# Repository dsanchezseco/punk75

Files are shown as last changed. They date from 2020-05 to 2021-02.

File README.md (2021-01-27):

# punk75
Ortholinear keyboard with 75 keys and all components through hole

Uses an ATmega32A-PU and USB-C.

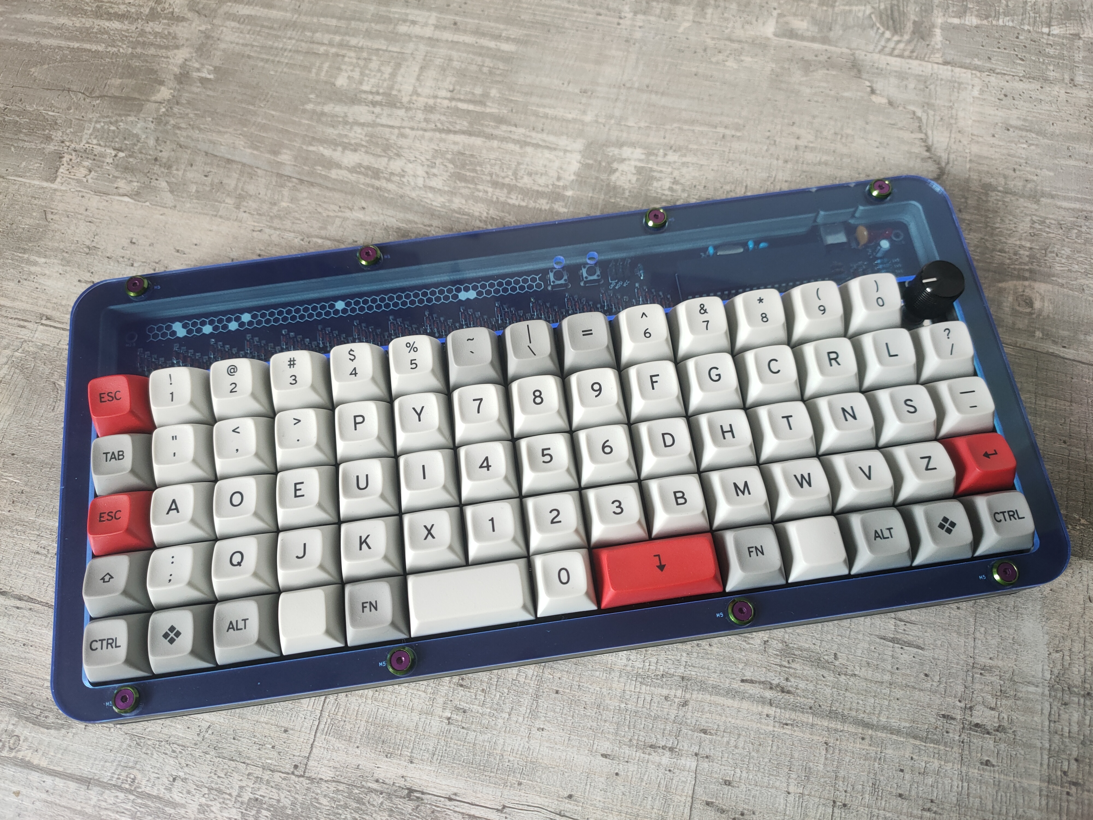
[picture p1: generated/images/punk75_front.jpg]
full keyboard front

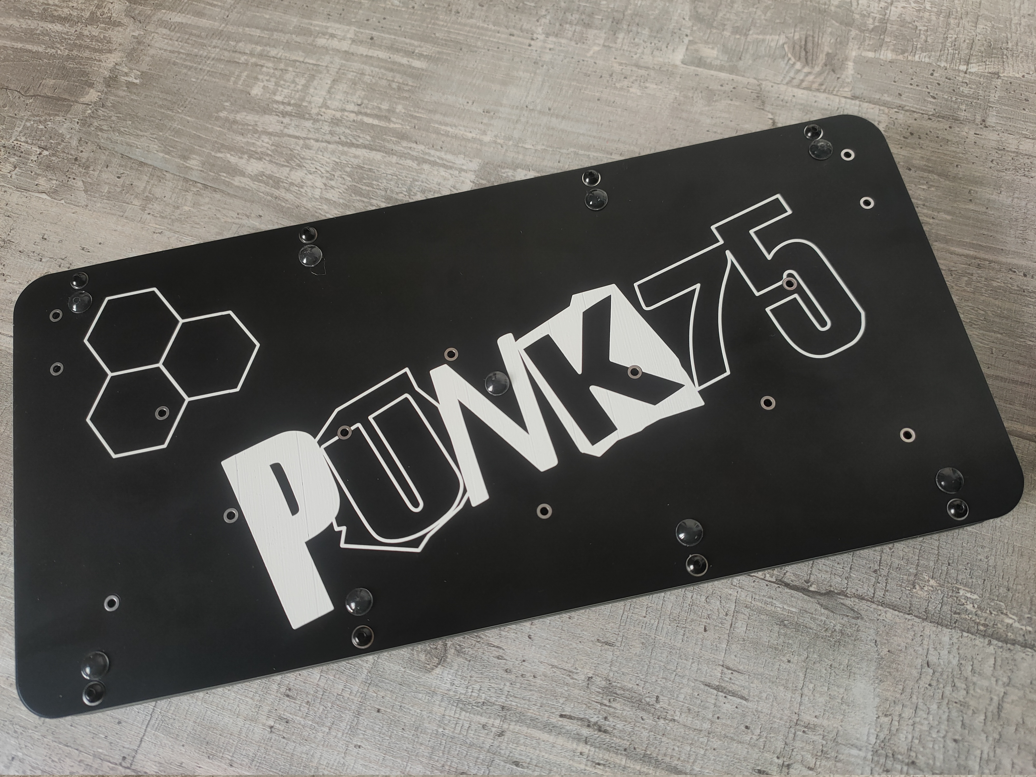
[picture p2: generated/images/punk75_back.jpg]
full keyboard back

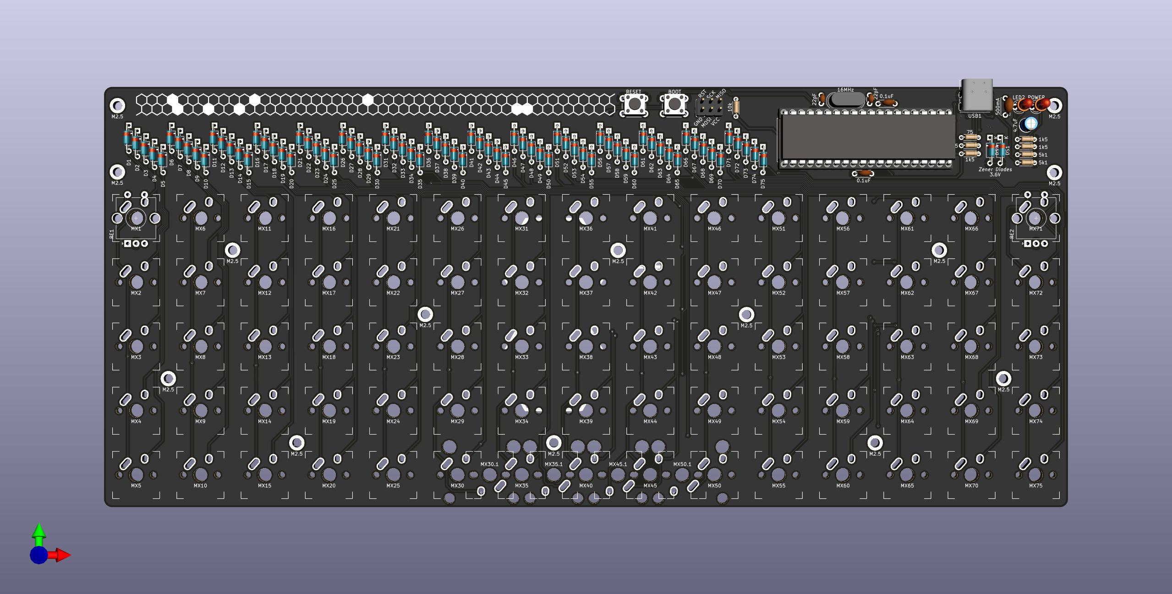
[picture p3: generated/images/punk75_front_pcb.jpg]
front of pcb

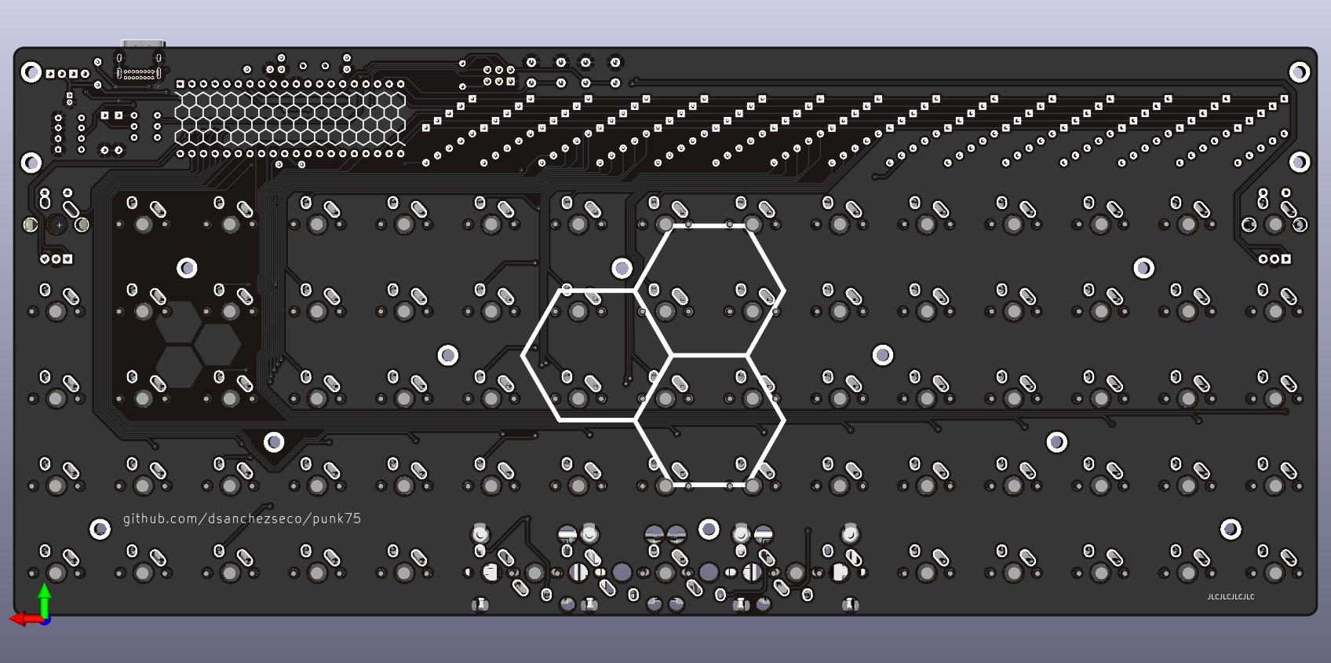
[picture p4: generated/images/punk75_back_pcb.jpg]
back of pcb

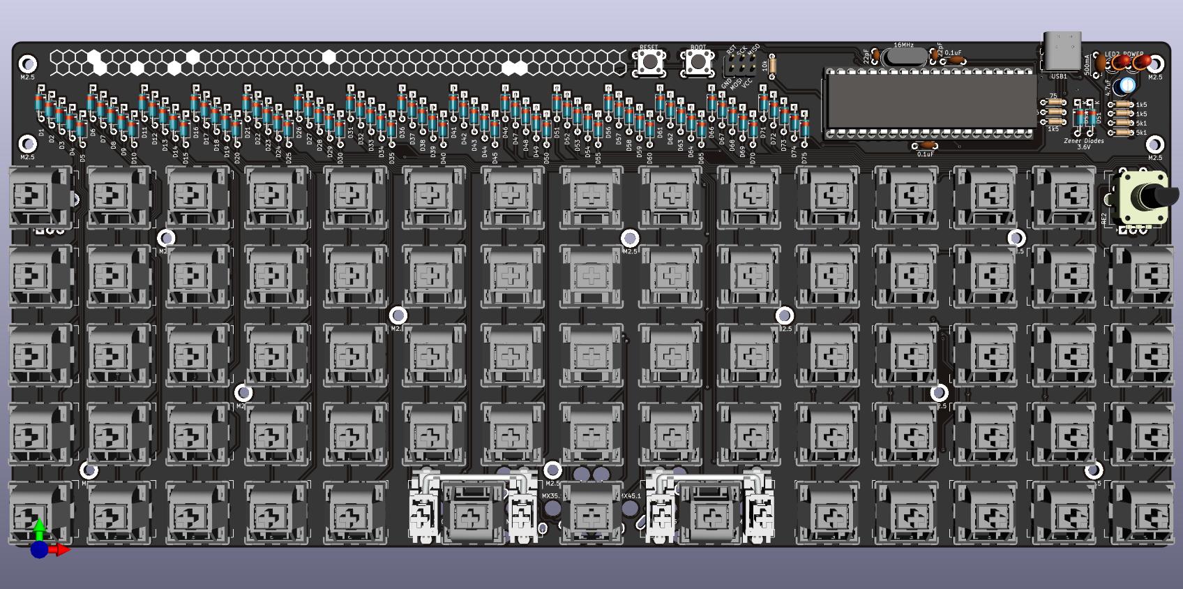
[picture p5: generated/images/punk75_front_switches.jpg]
with switches


# BOM list
[BOM list](https://octopart.com/bom-tool/D58T7Rv1)

# Building
[Building guide](https://github.com/dsanchezseco/punk75/blob/master/BUILDING.md)

# Bootloader flashing

Before being able to flash the keymap as regular in QMK using a USB we need to
flash the bootloader first. It is only needed to do this process once if the MCU
does not come already flashed with a bootloader.

Punk75 uses [USBasp](https://www.fischl.de/usbasp/) as bootloader.

To flash USBasp you'll need and *USBasp dongle* or a *pro micro/elite-c*.
Other methods not tested but may work.

To follow the process to flash the bootloader [go here](https://github.com/dsanchezseco/USBaspLoader)
and follow the instructions.

# Keymap flashing
There are two possibilities

## QMK toolbox
TODO

## CLI
TODO

# Cases

## PCB
[PCB case](https://github.com/dsanchezseco/punk75/blob/master/case/PCB/README.md)

## Acrylic
[Acrylic case](https://github.com/dsanchezseco/punk75/blob/master/case/sandwich/README.md)

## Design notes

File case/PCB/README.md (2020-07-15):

# Case made out of PCBs

This is an alternative to the acrylic case. It has the same dimenssions and form
but it is made out of (more) layers of PCBs instead of acrylic.

## Parts (top to bottom)

1. punk75_inner.zip - PCB - 4 needed - OPTIONAL FOR HI-PRO CASE
2. punk75_plate.zip - PCB
3. punk75_inner.zip - PCB - 5 needed
4. punk75_bottom.zip- PCB

This parts can be sourced from a PCB manufacturer with the .zip files of this
folder.

## Screws and Standoffs

1. x16 M3x6mm screws
2. x8  M3x10mm round standoffs of 5mm outside diameter
    (for the HI-PRO use M3x15mm)

## Assembly

For the assembly of all the parts we need to first place the switches on the
plate and then proceed to solder them to the keyboard PCB (solder first the
rotary encoders to the pcb if any).

Then we can proceed form bottom to top by screwing the spacers to the bottom and
inserting the inners in the standoffs. Notice the inners have breakable zone
where the USB port is placed, this need to be snipped or cut. Cut the needed
amount to fit your cable(is a bit tight, I have on mine 1 not cutted and 4 with
the cutout, test with yours).

Next place the plate and you are good to go.

If you have the HI-PRO place then the rest of the inners (not cutted) and screw
everything.

## Acrylic shield

Additionally two acrylic shields can be used to protect the electronic components.
One, a full shield (shield.dxf) can be used with the HI-PRO case (and with the
LO-PRO if the components are mounted low).

The other option is to use a half shield (half-shield.dxf) that instead of using
the rest of the case as support uses its own standoffs to held it down to the PCB.

This standoffs and screws for the half-shield are M2.5 size, use the lenght you
feel appropiate. You'll need 4 standoffs and 8 screws.

To know how to source this acrylic pieces refeer to the sandwich case README.md

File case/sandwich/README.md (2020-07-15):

# Acrylic High Profile case

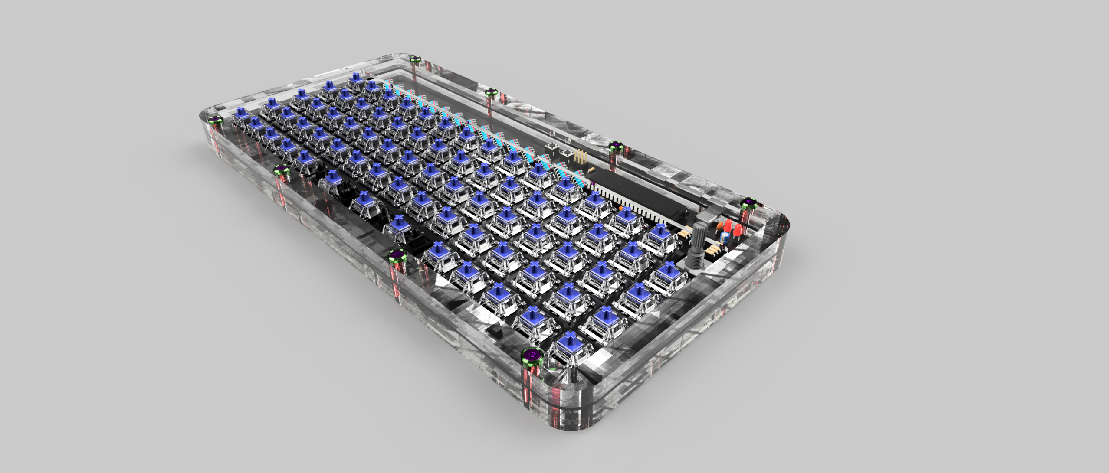
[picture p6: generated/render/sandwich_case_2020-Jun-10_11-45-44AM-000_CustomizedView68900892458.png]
sandwich case render


Case of sandwich style made out of acrylic(plate made out of Delrin for extra rigidity).

__I recommend using [Ponoko](https://www.ponoko.com/) to cut the pieces. They have all of the correct/required thicknesses and materials in stock and have the best pricing that I have found for multiple one-off parts. Use clear acrylic for the full range of thickness options and Delrin (POM) for the plate. For proper fit please ensure you use the correct dimensions and material thicknesses noted below. Other colors may be used, but of the colors may have limited thickness options, so you may have to narrow material results by thickness to see which colors are available for that size.__

__Ponoko's automatic size detection when uploading is not flawless, so be sure to manually enter the dimensions below.__

## Parts (top to bottom)

1. shield.dxf  - 307.7 x 146.6 - 2 mm thickness - acrylic
2. closed.dxf  - 307.7 x 146.6 - 3 mm thickness - acrylic
3. closed.dxf  - 307.7 x 146.6 - 3 mm thickness - acrylic
4. plate.dxf   - 307.7 x 146.6 - 1.5 mm thickness - *Delrin*
5. open.dxf    - 307.7 x 146.6 - 4.5 mm thickness - acrylic
6. closed.dxf  - 307.7 x 146.6 - 3 mm thickness - acrylic
7. bottom.dxf  - 307.7 x 146.6 - 3 mm thickness - acrylic

__Closed layer is used three times!__

You can choose any type of material/finish for the layers, but notice the required thicknes! For the plate layer Delrin is used because of the extra rigidity compared with regular acrylic, but it only comes in white or black.

## Screws and Standoffs

1. x16 M3x6 screws
2. x8  M3x15 round standoffs of 5mm outside diameter

#### Optional
If using conic screws as in the renders M3 conic washers (8mm) are also required.q

### Credits

Dimensions, intro and general form of the case taken from [coseyfannitutti](https://github.com/coseyfannitutti/discipline/blob/master/case/README.md)

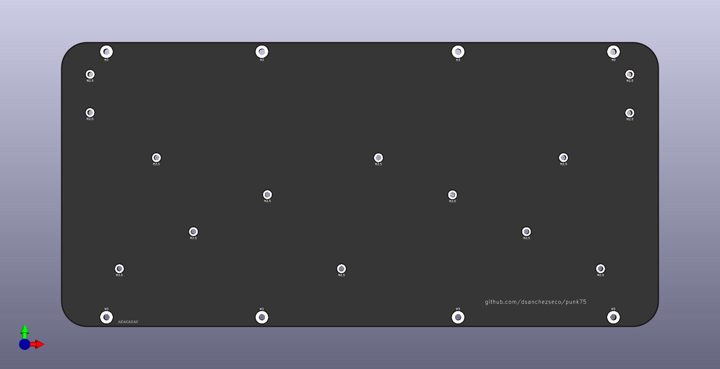
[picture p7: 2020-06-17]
generated/images/punk75_bottom_front.jpg

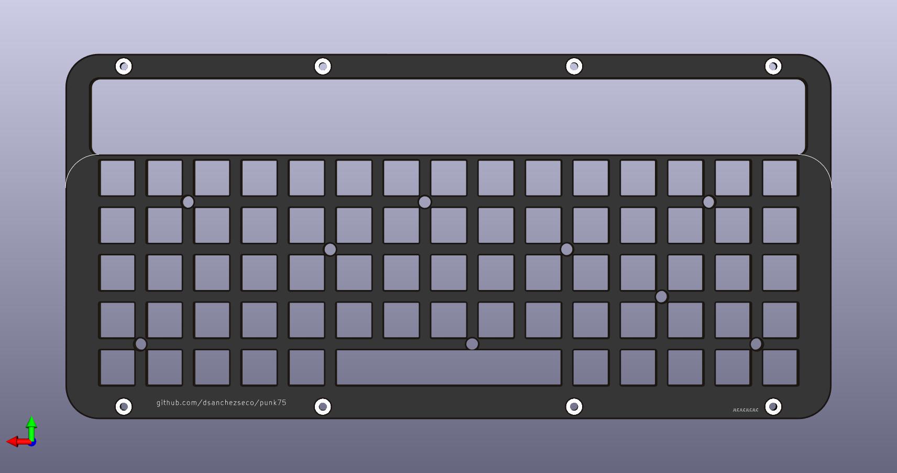
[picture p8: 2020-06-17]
generated/images/punk75_plate_back.jpg

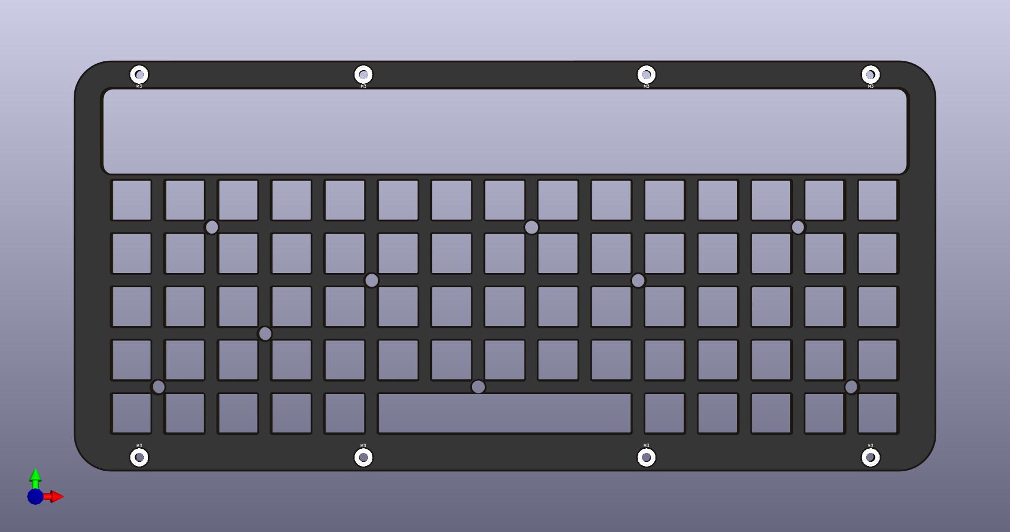
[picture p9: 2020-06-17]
generated/images/punk75_plate_front.jpg

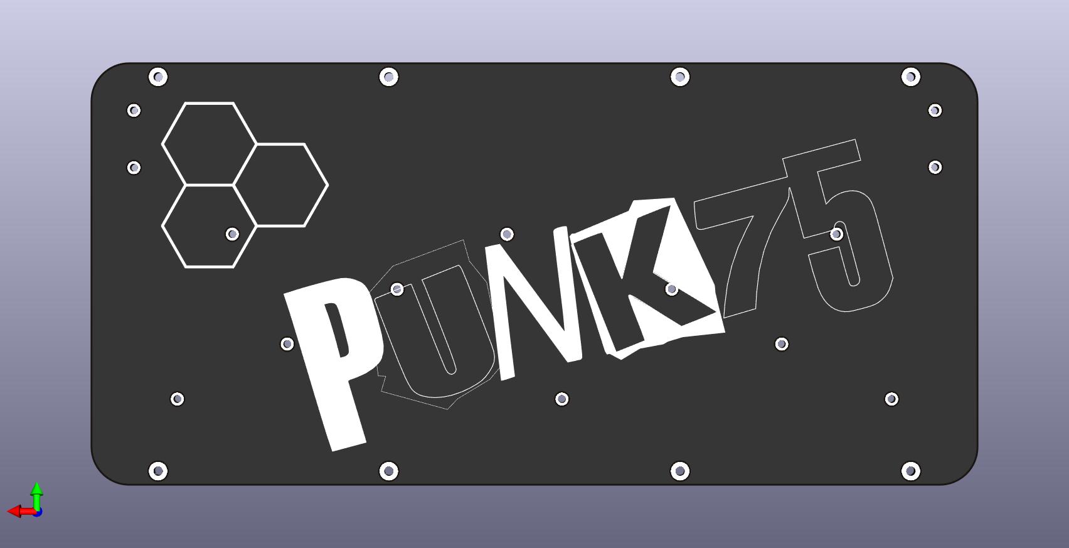
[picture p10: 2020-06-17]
generated/images/punk75_bottom_back.jpg

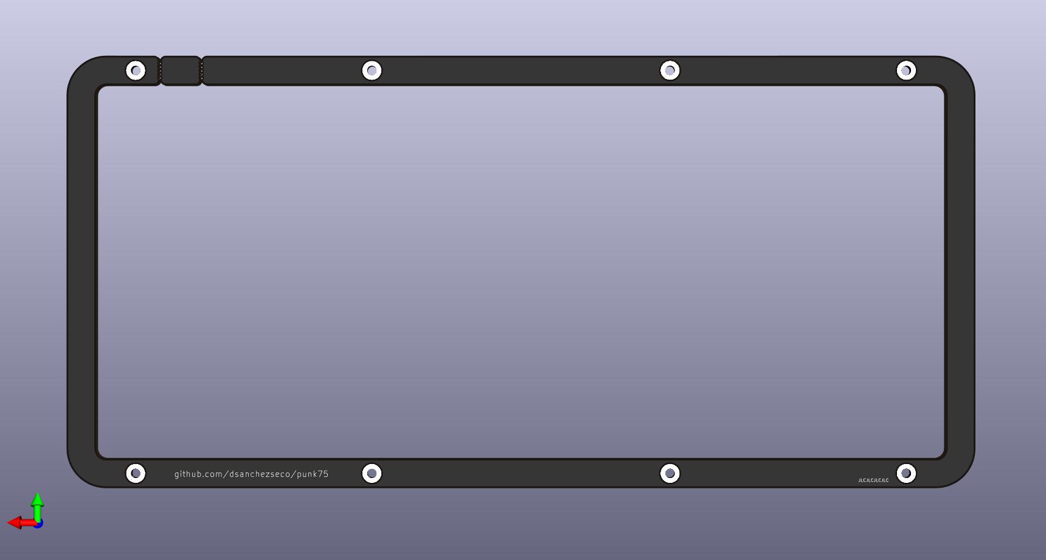
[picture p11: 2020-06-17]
generated/images/punk75_inner_back.jpg

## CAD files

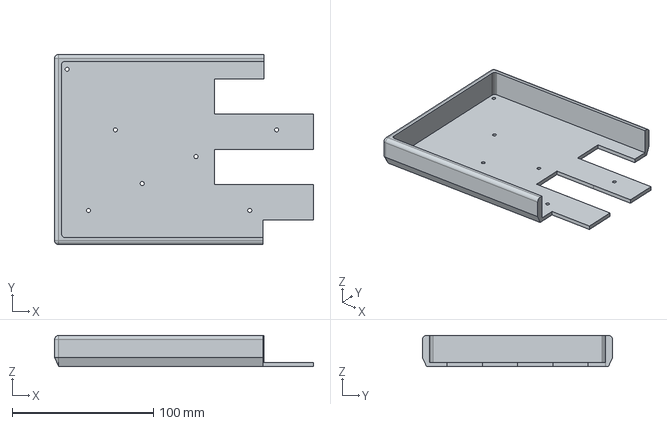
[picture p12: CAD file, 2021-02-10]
case/3D_Printed/Simple High Profile Case/Punk75 HP - Left Side.step
183.5 x 134.9 x 22.0 mm

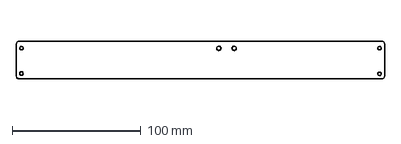
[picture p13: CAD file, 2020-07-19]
case/PCB/half-shield.dxf
285.8 x 29.4 mm

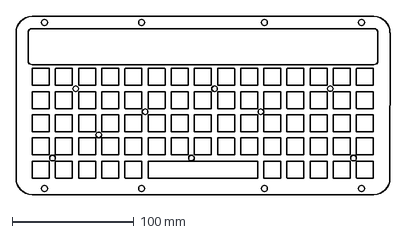
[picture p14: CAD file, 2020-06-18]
case/sandwich/plate.dxf
307.8 x 146.6 mm

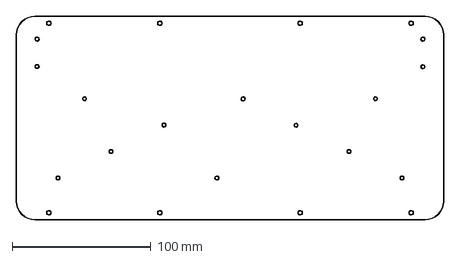
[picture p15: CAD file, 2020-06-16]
case/sandwich/bottom.dxf
307.8 x 146.6 mm

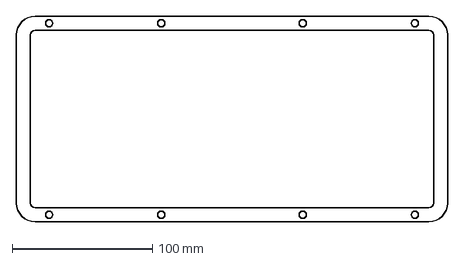
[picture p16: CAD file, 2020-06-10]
case/sandwich/closed.dxf
307.8 x 146.6 mm

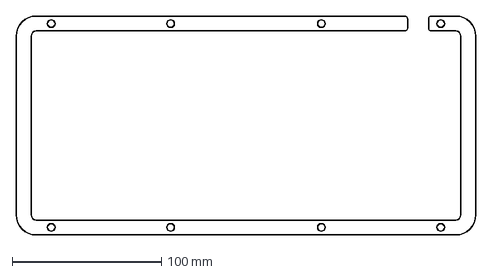
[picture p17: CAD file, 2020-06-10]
case/sandwich/open.dxf
307.8 x 146.6 mm

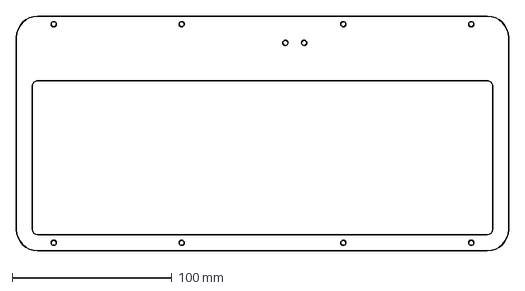
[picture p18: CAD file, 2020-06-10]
case/sandwich/shield.dxf
307.8 x 146.6 mm

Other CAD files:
case/3D_Printed/Simple High Profile Case/Punk75 HP - Right Side.step
case/PCB/shield.dxf
case/3D_Printed/Simple High Profile Case/Punk75 HP - Left Side.stl
case/3D_Printed/Simple High Profile Case/Punk75 HP - Right Side.stl

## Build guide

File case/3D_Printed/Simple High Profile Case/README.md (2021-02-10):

# 3d Printed Case Production and Assembly Notes

## Overview

The 3d printed cases in this directory should all follow these assembly instructions. They have also been designed to use the half shield .dxf here: https://github.com/dsanchezseco/punk75/blob/master/case/sandwich/half-shield.dxf

## Case Designer Index

| Case Design | Author |
|---|---|
| Simple High Profile Case | jmo808 |

## Sample Pics

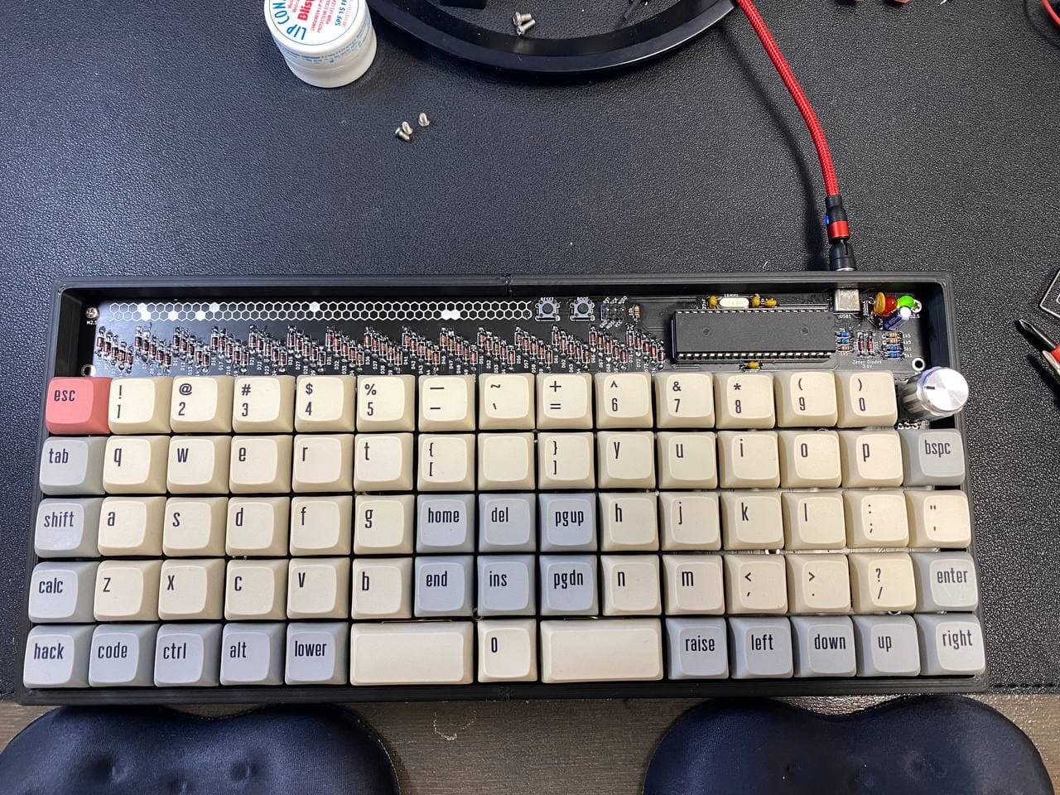
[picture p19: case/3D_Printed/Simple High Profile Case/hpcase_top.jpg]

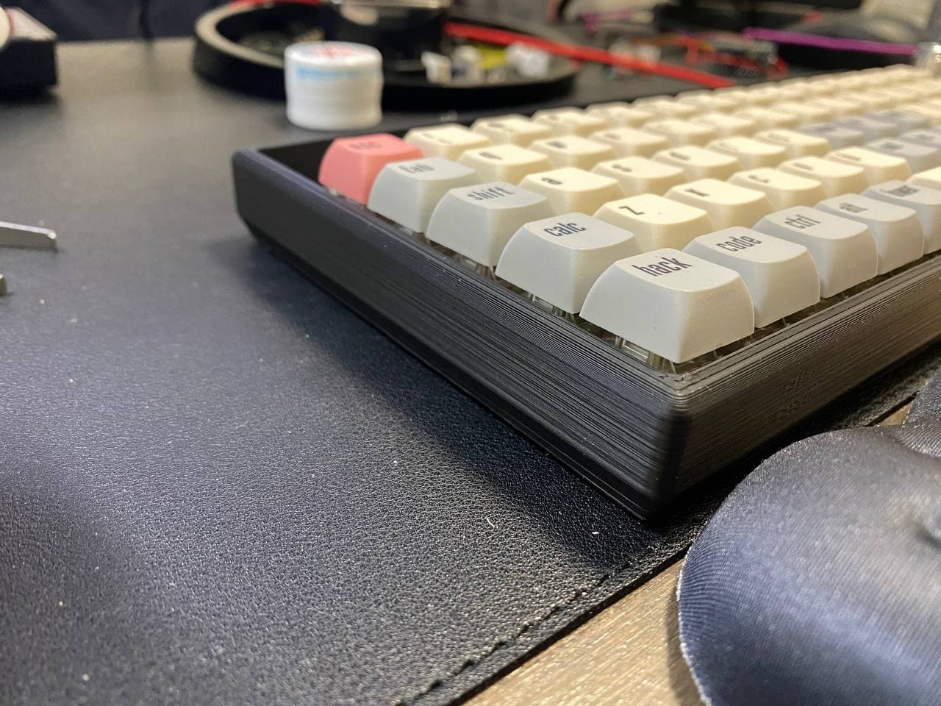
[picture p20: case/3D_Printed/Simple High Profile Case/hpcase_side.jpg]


## Required Parts

* (12) M2.5 5mm Standoffs
* (12) M2.5 6mm Pan/Button Head machine screws (for bottom of case to standoffs)
* (12) M2.5 3mm Pan/Button Head machine screws (for PCB to standoffs)

## Printing Settings

This was printed with .2 layer height. Lower layers will have a smoother appearance at the risk of much longer print time.

## Assembly Instructions

Once both halves are printed clean up any artifacts and "elephant foot" so that both halves fit nicely.

Install the standoffs with the 6mm screws then use the PCB to secure the halves together. Some filaments have more shrinkage than others and using the PCB as a guide will ensure that the case is assembled square. You will then have the opportunity to fill any gaps vs creating a case that is too small.

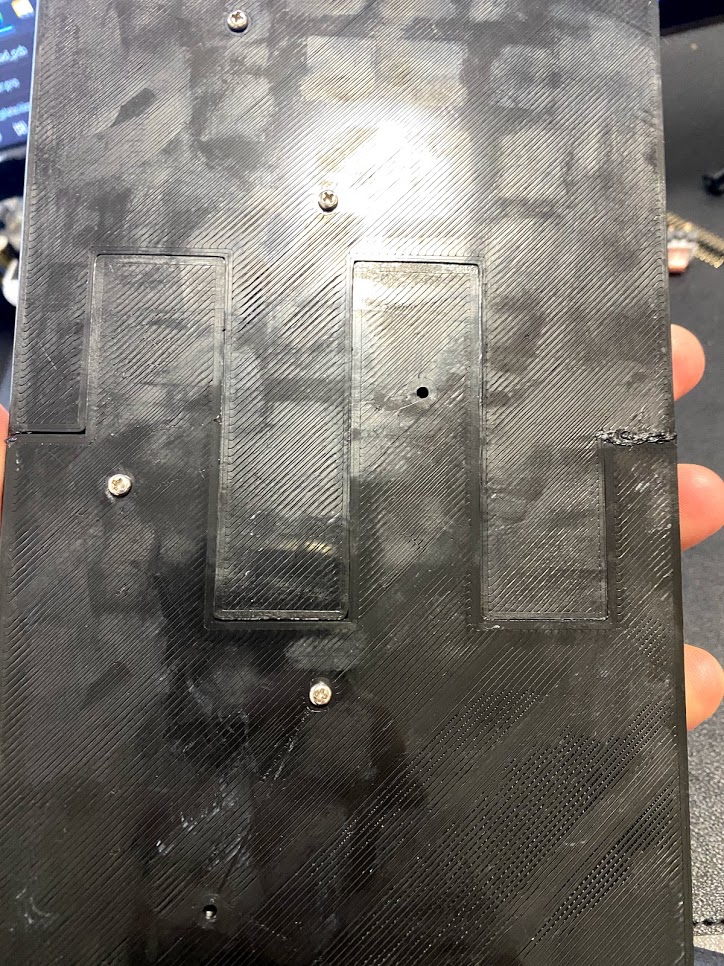
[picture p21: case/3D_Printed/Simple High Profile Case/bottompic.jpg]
Bottom View


Once the PCB is affixed to the standoffs on both halves you can either glue or friction weld the outside of the case together. Friction welding is recommended as it is more mechanically sound, but needs more significant post-processing if a more professional appearance is desired. If you are choosing to use the friction welding method, you will require a high speed handheld rotary tool.

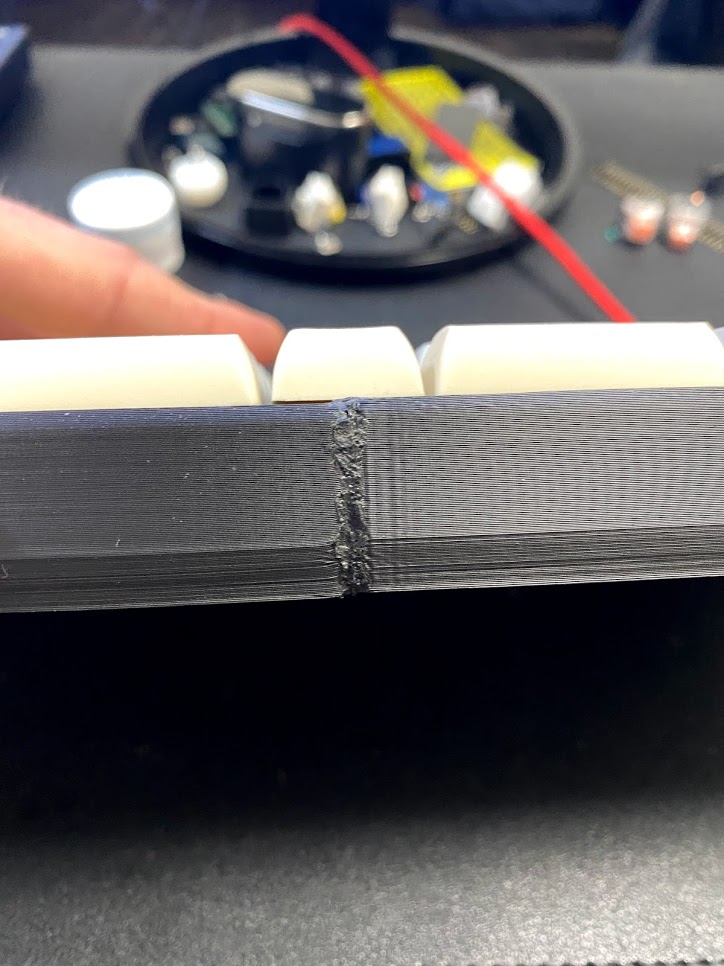
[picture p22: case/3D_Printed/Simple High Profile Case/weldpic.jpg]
Sample Weld Pic


The technique is shown here: https://www.youtube.com/watch?v=Pa2DoE3sirU.

If the only filament you have is 1.75mm you will need to insert two pieces of filament and cut one flush to the collet of your rotary tool this will secure the 1.75mm filament vs. going and buying 2.85mm filament just to friction weld. Left over bits on filament rolls are a perfect source of friction welding material.

**SAFETY NOTE**: *Wear wrap around safety glasses or goggles when friction welding as bits of plastic can shoot out and injure you.*

Once the bottom of the case is welded you can remove the PCB and friction weld the inside of the case for added strength.

## Post Processing

For a more refined appearance I suggest sanding and polishing. My recommendation is to use an orbital sander with Abranet disks as they are much cooler than regular sanding disks and will prevent PLA from getting gummy. Start with 120 grit to remove layer lines, then move on to 220 grit, then 400 grit and follow up with wet hand sanding at 400 grit and final wet hand polishing at 2000 grit.

## Final Assembly

Re-install the populated PCB, install keycaps and enjoy!

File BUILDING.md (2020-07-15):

# Building guide
This file cover all the building(soldering) needed to get your punk75 up and running.

All the spots in the PCB are labeled with the value of the component that goes in that spot,
so it should be fairly easy, you only need to pay attention to the components that have orientation.

Start with the smallest components like the resistors. They have no orientation.
Then place the Zenner Diodes (DS1 & DS2), this two have orientation, so take care to match the line
of the component with the line(square hole) of the pcb.

Continue with the capacitors that go arround the MCU and the crystal, they have no orientation, pay
attention to leave room for the MCU that will be placed later.

Now place the LEDs, they have orientation, so put the shorter leg in the square hole.
The missing capacitor comes next and it also has orientation, the grey line/shorter leg goes in the grey hole.

Next place the fuse, it has no orientation.

Now comes the time for the MCU. You can choose to solder it directly to the PCB, it'll rest lower but if it breaks
would be way harder to replace. I recommend you to use the MCU socket. Pay attention to the orientation and match the
socket and MCU notches with the PCB painted one.

Then add the push buttons and the optional 3x2 pins.

Finish by soldering the USB-C port and its tiny pins(good luck), the flux and using a low amount of solder
is quite helpfull here.

Now you are ready to test your keyboard, connect a usb cable, check there's no smoke and the right LED powers on.
If you short the two pins of a switch and its diode the left LED should power on while held.

If everything went smooth you are ready to finish it by soldering the diodes(mind the orientation as in the zenners)
and the swithes.

Well done!

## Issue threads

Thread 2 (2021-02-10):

Simple High Profile 3d Printed Case

jmo808, 2021-02-10:
I've designed a simple high profile 3d printed case. It comes as two parts in order to print on most printers with alignment tabs for gluing/welding. Instead of posting it on Thingiverse I'd rather include it here in order to keep things together. I can profile STL and STEP file. If you are ok with incorporating the case in your repo, I will do a PR.

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

dsanchezseco, 2021-02-10:
Sure, go ahead, it looks awesome!! I'm regreting now not having a 3D printer :(

jmo808, 2021-02-10:
3d printers are almost as much of a time suck as mech keyboards so maybe it's a good thing you don't have one, though I definitely like having one! I will submit PR today sometime.

Closed 2021-02-10.

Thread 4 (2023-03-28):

Keypress issues

vialde, 2023-03-28:
Morning,

Just wanted to say how happy I am that you've open sourced this design...I really like it.  I've got a quick question.  I'm having issues with my build.  I've had the PCBs fab'd and soldered on all the components.  Flashed the firmware using the instructions in your other repo....everything looked good.  Unfortunately it's not registering keypresses.  I'm new to the Keyboard pcb game...I've done a few hand wired boards using pro micros, but I'm not sure what to troubleshoot here.  Both led's light up when the usb cable is plugged in...that's the only response I get.  Any thoughts or tips?
Cheers

dsanchezseco, 2023-04-03:
Hi! glad you like it and honored you build it!

The other repo is the bootloader, the only thing I can think of is that you might be missing the actual keymap.

it would be a regular QMK flash process now that you have the bootloader. One of the leds should blink when a keypress is registered. If I remember correctly with the bootloader only it just turned on to tell you the bootloader is correctly in.

It's being a while since I created and I barely remember the process 😅

vialde, 2023-04-19:
Hey, that might be the issue.  I thought the bootloader contained everything.  okay.  so the question is now...can I flash via the usb c or do I need to used the adapter again?

dsanchezseco, 2023-04-19:
USB-C just hold the boot button, plug it in or press reset, hold the boot a couple seconds more and the you are good to do the flash with QMK

-------- Original Message --------
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

dsanchezseco, 2023-04-19:
Is it working then?? Enjoy it!! I loved making and using it, i hope you do as well!

-------- Original Message --------
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

vialde, 2023-05-01:
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
Working like a charm!  Now for a case!

Closed 2023-05-01.

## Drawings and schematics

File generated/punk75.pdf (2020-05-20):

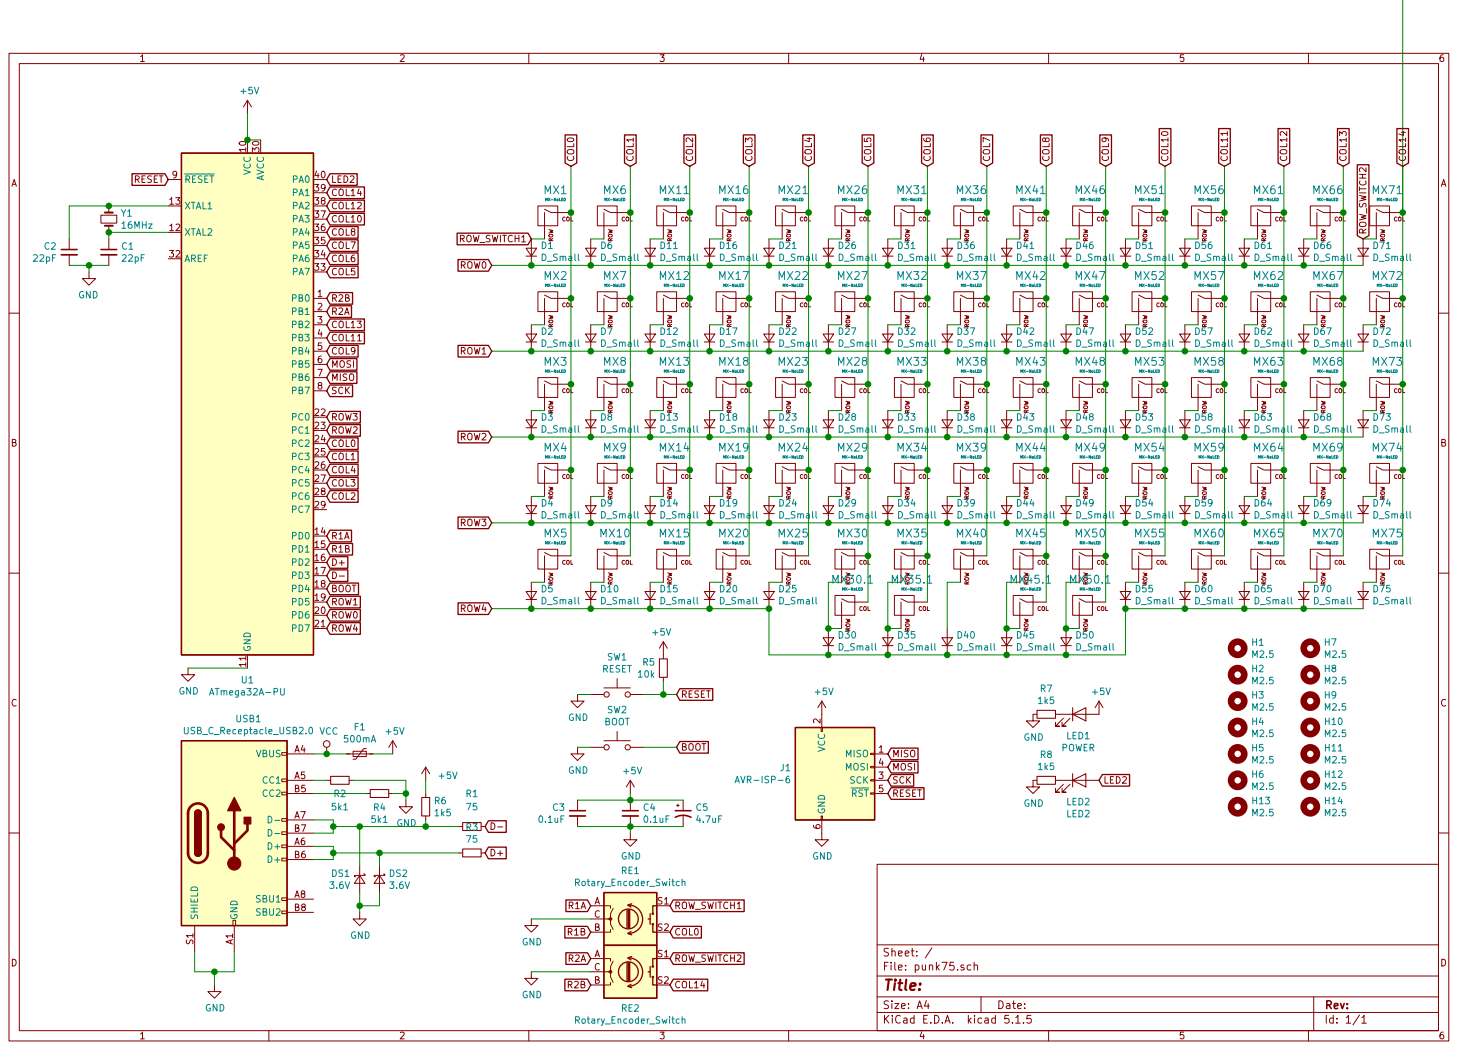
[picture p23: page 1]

MX-NoLED D72 D_Small COL ROW MX72

MX-NoLEDCOL ROW MX6
MX-NoLED D67 D_Small COL ROW MX8

MX-NoLED D22 D_Small COL ROW MX22
MX-NoLED D18 D_Small COL ROW MX18

MX-NoLED D27 D_Small COL ROW MX27

MX-NoLED D46 D_Small COL ROW MX46
MX-NoLED D48 D_Small COL ROW MX48

MX-NoLED D52 D_Small COL ROW MX52

MX-NoLED D57 D_Small COL ROW MX57

MX-NoLED D62 D_Small COL ROW MX62

D42 D_Small COL ROW MX32
MX-NoLED D34 D_Small COL ROW MX34

MX-NoLED COL ROW MX47
MX-NoLED D43 D_Small COL ROW MX43

MX-NoLED D54 D_Small COL ROW MX54
MX-NoLED COL ROW MX68
MX-NoLED D65 D_Small COL ROW MX65

MX-NoLED D23 D_Small COL ROW MX23

MX-NoLED D28 D_Small COL ROW MX28

MX-NoLED D47 D_Small D33 D_Small COL ROW MX33

MX-NoLED D38 D_Small COL ROW MX38

MX-NoLED D58 D_Small COL ROW MX58

MX-NoLED D63 D_Small COL ROW MX63

MX-NoLED D74 D_Small COL ROW MX74

MX-NoLED D39 D_Small COL ROW MX39

COL ROW MX13
MX-NoLED D20 D_Small COL ROW MX20

MX-NoLED D29 D_Small COL ROW MX29

MX-NoLED D49 D_Small COL ROW MX49

MX-NoLED D24 D_Small COL ROW MX14
MX-NoLED D15 D_Small COL ROW MX15

MX-NoLED D25 D_Small COL ROW MX25

MX-NoLED D40 D_Small COL ROW MX40

MX-NoLED D55 D_Small COL ROW MX55

MX-NoLED D60 D_Small COL ROW MX60

MX-NoLED D70 D_Small COL ROW MX70

2 SCK 3 MOSI 4 RST 5 GND

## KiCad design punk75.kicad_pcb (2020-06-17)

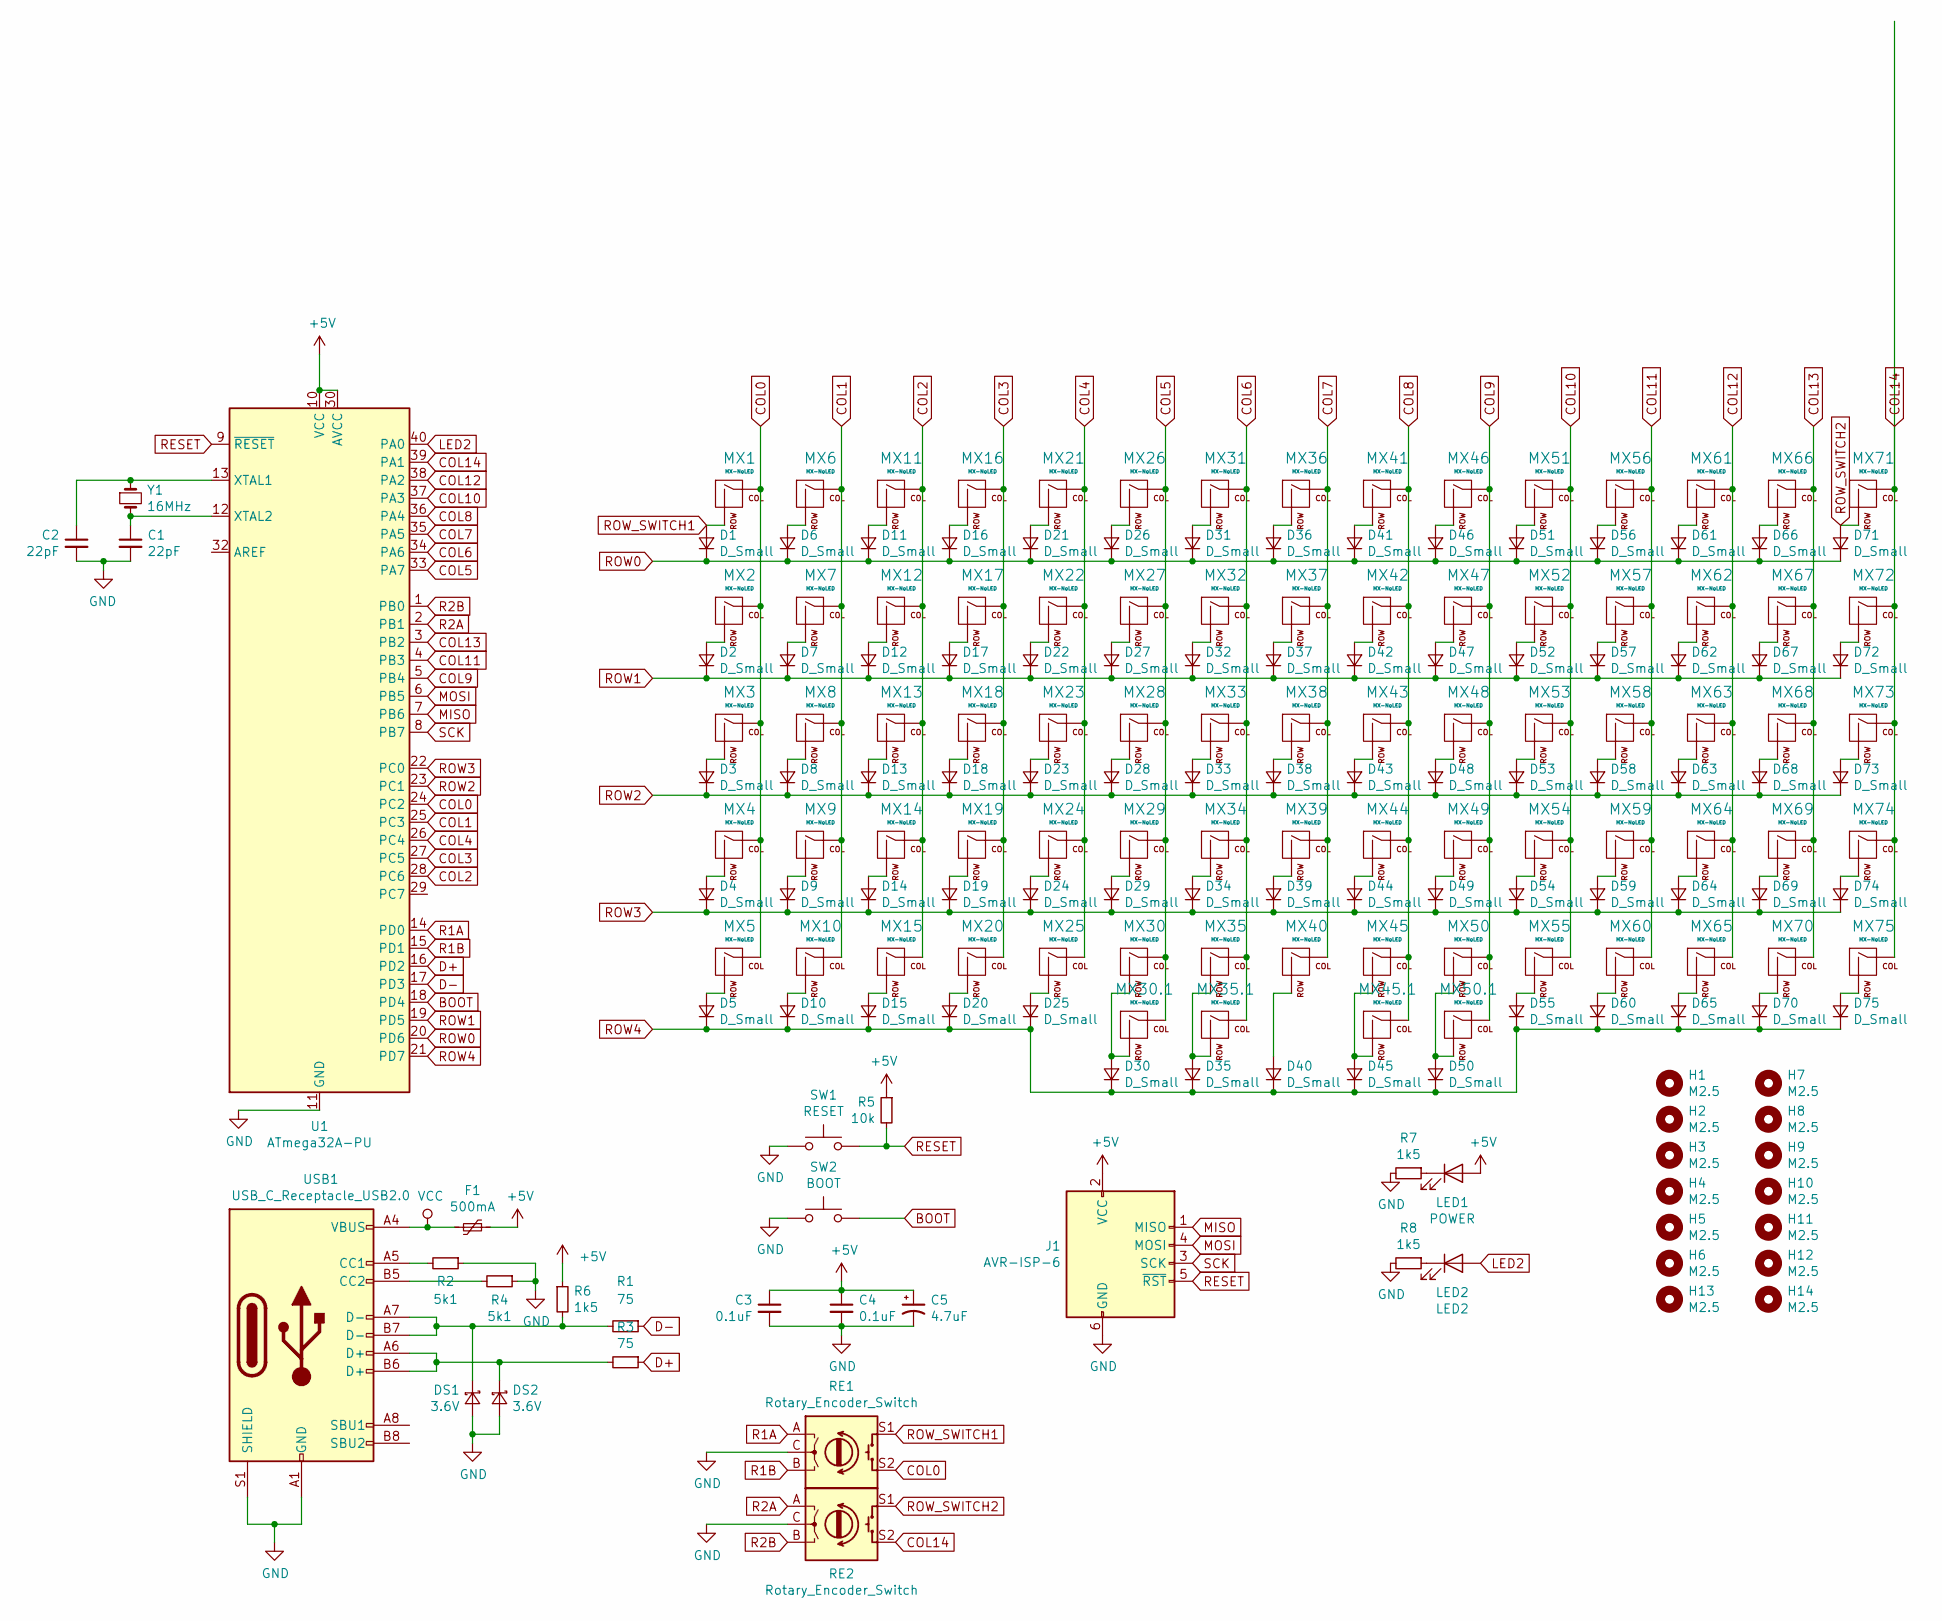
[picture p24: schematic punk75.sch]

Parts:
C1, C2: 22pF; C_Disc_D3.0mm_W1.6mm_P2.50mm
C3, C4: 0.1uF; C_Disc_D4.3mm_W1.9mm_P5.00mm
C5: 4.7uF; CP_Radial_D4.0mm_P1.50mm
D1, D2, D3, D4, D5, D6, D7, D8, D9, D10, D11, D12, D13, D14, D15, D16, D17, D18, D19, D20, D21, D22, D23, D24, D25, D26, D27, D28, D29, D30, D31, D32, D33, D34, D35, D36, D37, D38, D39, D40, D41, D42, D43, D44, D45, D46, D47, D48, D49, D50, D51, D52, D53, D54, D55, D56, D57, D58, D59, D60, D61, D62, D63, D64, D65, D66, D67, D68, D69, D70, D71, D72, D73, D74, D75: D_Small; D_DO-35_SOD27_P7.62mm_Horizontal
DS1, DS2: 3.6V; D_DO-35_SOD27_P7.62mm_Horizontal
F1: 500mA; C_Disc_D5.0mm_W2.5mm_P5.00mm
H1, H2, H3, H4, H5, H6, H7, H8, H9, H10, H11, H12, H13, H14: M2.5; MountingHole_2.7mm_M2.5_ISO7380_Pad
J1: AVR-ISP-6; Reset_Pretty-Mask
LED1: POWER; LED_D3.0mm
LED2: LED2; LED_D3.0mm
MX1, MX2, MX3, MX4, MX5, MX6, MX7, MX8, MX9, MX10, MX11, MX12, MX13, MX14, MX15, MX16, MX17, MX18, MX19, MX20, MX21, MX22, MX23, MX24, MX25, MX26, MX27, MX28, MX29, MX30, MX31, MX32, MX33, MX34, MX35, MX36, MX37, MX38, MX39, MX40, MX41, MX42, MX43, MX44, MX45, MX46, MX47, MX48, MX49, MX50, MX51, MX52, MX53, MX54, MX55, MX56, MX57, MX58, MX59, MX60, MX61, MX62, MX63, MX64, MX65, MX66, MX67, MX68, MX69, MX70, MX71, MX72, MX73, MX74, MX75: MX-NoLED; MX-1U-NoLED
MX30.1, MX35.1, MX45.1, MX50.1: MX-NoLED; MX-2U-NoLED
R1, R3: 75; R_Axial_DIN0204_L3.6mm_D1.6mm_P5.08mm_Horizontal
R2, R4: 5k1; R_Axial_DIN0204_L3.6mm_D1.6mm_P5.08mm_Horizontal
R5: 10k; R_Axial_DIN0204_L3.6mm_D1.6mm_P5.08mm_Horizontal
R6, R7, R8: 1k5; R_Axial_DIN0204_L3.6mm_D1.6mm_P5.08mm_Horizontal
RE1, RE2: Rotary_Encoder_Switch; RotaryEncoder_Alps_EC11E-Switch_Vertical_H20mm_CircularMoun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
SW1: RESET; SW_PUSH_6mm
SW2: BOOT; SW_PUSH_6mm
U1: ATmega32A-PU; DIP-40_W15.24mm
USB1: USB_C_Receptacle_USB2.0; USB_C_Receptacle_GCT_USB4085
Y1: 16MHz; Crystal_HC49-4H_Vertical

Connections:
+5V: C3.1, C4.1, C5.1, F1.1, J1.2 (VCC), LED1.2 (A), R5.1, R6.1, U1.10 (VCC), U1.30 (AVCC)
BOOT: SW2.2, U1.18 (PD4)
COL0: MX1.1 (COL), MX2.1 (COL), MX3.1 (COL), MX4.1 (COL), MX5.1 (COL), RE1.S2, U1.24 (PC2)
COL1: MX6.1 (COL), MX7.1 (COL), MX8.1 (COL), MX9.1 (COL), MX10.1 (COL), U1.25 (PC3)
COL2: MX11.1 (COL), MX12.1 (COL), MX13.1 (COL), MX14.1 (COL), MX15.1 (COL), U1.28 (PC6)
COL3: MX16.1 (COL), MX17.1 (COL), MX18.1 (COL), MX19.1 (COL), MX20.1 (COL), U1.27 (PC5)
COL4: MX21.1 (COL), MX22.1 (COL), MX23.1 (COL), MX24.1 (COL), MX25.1 (COL), U1.26 (PC4)
COL6: MX31.1 (COL), MX32.1 (COL), MX33.1 (COL), MX34.1 (COL), MX35.1 (COL), MX35.1.1 (COL), U1.34 (PA6)
COL7: MX36.1 (COL), MX37.1 (COL), MX38.1 (COL), MX39.1 (COL), MX40.1 (COL), U1.35 (PA5)
COL8: MX41.1 (COL), MX42.1 (COL), MX43.1 (COL), MX44.1 (COL), MX45.1 (COL), MX45.1.1 (COL), U1.36 (PA4)
COL9: MX46.1 (COL), MX47.1 (COL), MX48.1 (COL), MX49.1 (COL), MX50.1 (COL), MX50.1.1 (COL), U1.5 (PB4)
COL10: MX51.1 (COL), MX52.1 (COL), MX53.1 (COL), MX54.1 (COL), MX55.1 (COL), U1.37 (PA3)
COL11: MX56.1 (COL), MX57.1 (COL), MX58.1 (COL), MX59.1 (COL), MX60.1 (COL), U1.4 (PB3)
COL12: MX61.1 (COL), MX62.1 (COL), MX63.1 (COL), MX64.1 (COL), MX65.1 (COL), U1.38 (PA2)
COL13: MX66.1 (COL), MX67.1 (COL), MX68.1 (COL), MX69.1 (COL), MX70.1 (COL), U1.3 (PB2)
COL14: MX71.1 (COL), MX72.1 (COL), MX73.1 (COL), MX74.1 (COL), MX75.1 (COL), RE2.S2, U1.39 (PA1)
D+: R3.1, U1.16 (PD2)
D-: R1.1, U1.17 (PD3)
GND: C1.2, C2.2, C3.2, C4.2, C5.2, DS1.2 (A), DS2.2 (A), J1.6 (GND), R2.1, R4.1, R7.2, R8.2, RE1.C, RE2.C, SW1.2, SW2.1, U1.11 (GND), U1.31 (GND), USB1.A1 (GND), USB1.A12 (GND), USB1.B1 (GND), USB1.B12 (GND), USB1.S1 (SHIELD)
LED2: LED2.2 (A), U1.40 (PA0)
MISO: J1.1 (MISO), U1.7 (PB6)
MOSI: J1.4 (MOSI), U1.6 (PB5)
unnamed: C1.1, U1.12 (XTAL2), Y1.2
unnamed: C2.1, U1.13 (XTAL1), Y1.1
unnamed: D2.2 (A), MX2.2 (ROW)
unnamed: D3.2 (A), MX3.2 (ROW)
unnamed: D4.2 (A), MX4.2 (ROW)
unnamed: D5.2 (A), MX5.2 (ROW)
unnamed: D6.2 (A), MX6.2 (ROW)
unnamed: D7.2 (A), MX7.2 (ROW)
unnamed: D8.2 (A), MX8.2 (ROW)
unnamed: D9.2 (A), MX9.2 (ROW)
unnamed: D10.2 (A), MX10.2 (ROW)
unnamed: D11.2 (A), MX11.2 (ROW)
unnamed: D12.2 (A), MX12.2 (ROW)
unnamed: D13.2 (A), MX13.2 (ROW)
unnamed: D14.2 (A), MX14.2 (ROW)
unnamed: D15.2 (A), MX15.2 (ROW)
unnamed: D16.2 (A), MX16.2 (ROW)
unnamed: D17.2 (A), MX17.2 (ROW)
unnamed: D18.2 (A), MX18.2 (ROW)
unnamed: D19.2 (A), MX19.2 (ROW)
unnamed: D20.2 (A), MX20.2 (ROW)
unnamed: D21.2 (A), MX21.2 (ROW)
unnamed: D22.2 (A), MX22.2 (ROW)
unnamed: D23.2 (A), MX23.2 (ROW)
unnamed: D24.2 (A), MX24.2 (ROW)
unnamed: D25.2 (A), MX25.2 (ROW)
unnamed: D26.2 (A), MX26.2 (ROW)
unnamed: D27.2 (A), MX27.2 (ROW)
unnamed: D28.2 (A), MX28.2 (ROW)
unnamed: D29.2 (A), MX29.2 (ROW)
unnamed: D31.2 (A), MX31.2 (ROW)
unnamed: D32.2 (A), MX32.2 (ROW)
unnamed: D33.2 (A), MX33.2 (ROW)
unnamed: D34.2 (A), MX34.2 (ROW)
unnamed: D35.2 (A), MX35.2 (ROW), MX35.1.2 (ROW)
unnamed: D36.2 (A), MX36.2 (ROW)
unnamed: D37.2 (A), MX37.2 (ROW)
unnamed: D38.2 (A), MX38.2 (ROW)
unnamed: D39.2 (A), MX39.2 (ROW)
unnamed: D40.2 (A), MX40.2 (ROW)
unnamed: D41.2 (A), MX41.2 (ROW)
unnamed: D42.2 (A), MX42.2 (ROW)
unnamed: D43.2 (A), MX43.2 (ROW)
unnamed: D44.2 (A), MX44.2 (ROW)
unnamed: D45.2 (A), MX45.2 (ROW), MX45.1.2 (ROW)
unnamed: D46.2 (A), MX46.2 (ROW)
unnamed: D47.2 (A), MX47.2 (ROW)
unnamed: D48.2 (A), MX48.2 (ROW)
unnamed: D49.2 (A), MX49.2 (ROW)
unnamed: D50.2 (A), MX50.2 (ROW), MX50.1.2 (ROW)
unnamed: D51.2 (A), MX51.2 (ROW)
unnamed: D52.2 (A), MX52.2 (ROW)
unnamed: D53.2 (A), MX53.2 (ROW)
unnamed: D54.2 (A), MX54.2 (ROW)
unnamed: D55.2 (A), MX55.2 (ROW)
unnamed: D56.2 (A), MX56.2 (ROW)
unnamed: D57.2 (A), MX57.2 (ROW)
unnamed: D58.2 (A), MX58.2 (ROW)
unnamed: D59.2 (A), MX59.2 (ROW)
unnamed: D60.2 (A), MX60.2 (ROW)
unnamed: D61.2 (A), MX61.2 (ROW)
unnamed: D62.2 (A), MX62.2 (ROW)
unnamed: D63.2 (A), MX63.2 (ROW)
unnamed: D64.2 (A), MX64.2 (ROW)
unnamed: D65.2 (A), MX65.2 (ROW)
unnamed: D66.2 (A), MX66.2 (ROW)
unnamed: D67.2 (A), MX67.2 (ROW)
unnamed: D68.2 (A), MX68.2 (ROW)
unnamed: D69.2 (A), MX69.2 (ROW)
unnamed: D70.2 (A), MX70.2 (ROW)
unnamed: D72.2 (A), MX72.2 (ROW)
unnamed: D73.2 (A), MX73.2 (ROW)
unnamed: D74.2 (A), MX74.2 (ROW)
unnamed: D75.2 (A), MX75.2 (ROW)
unnamed: DS1.1 (K), R1.2, R6.2, USB1.A7 (D-), USB1.B7 (D-)
unnamed: DS2.1 (K), R3.2, USB1.A6 (D+), USB1.B6 (D+)
unnamed: LED1.1 (K), R7.1
unnamed: LED2.1 (K), R8.1
unnamed: R2.2, USB1.A5 (CC1)
unnamed: R4.2, USB1.B5 (CC2)
R1A: RE1.A, U1.14 (PD0)
R1B: RE1.B, U1.15 (PD1)
R2A: RE2.A, U1.2 (PB1)
R2B: RE2.B, U1.1 (PB0)
RESET: J1.5 (~RST), R5.2, SW1.1, U1.9 (~RESET)
ROW0: D1.1 (K), D6.1 (K), D11.1 (K), D16.1 (K), D21.1 (K), D26.1 (K), D31.1 (K), D36.1 (K), D41.1 (K), D46.1 (K), D51.1 (K), D56.1 (K), D61.1 (K), D66.1 (K), D71.1 (K), U1.20 (PD6)
ROW1: D2.1 (K), D7.1 (K), D12.1 (K), D17.1 (K), D22.1 (K), D27.1 (K), D32.1 (K), D37.1 (K), D42.1 (K), D47.1 (K), D52.1 (K), D57.1 (K), D62.1 (K), D67.1 (K), D72.1 (K), U1.19 (PD5)
ROW2: D3.1 (K), D8.1 (K), D13.1 (K), D18.1 (K), D23.1 (K), D28.1 (K), D33.1 (K), D38.1 (K), D43.1 (K), D48.1 (K), D53.1 (K), D58.1 (K), D63.1 (K), D68.1 (K), D73.1 (K), U1.23 (PC1)
ROW3: D4.1 (K), D9.1 (K), D14.1 (K), D19.1 (K), D24.1 (K), D29.1 (K), D34.1 (K), D39.1 (K), D44.1 (K), D49.1 (K), D54.1 (K), D59.1 (K), D64.1 (K), D69.1 (K), D74.1 (K), U1.22 (PC0)
ROW4: D5.1 (K), D10.1 (K), D15.1 (K), D20.1 (K), D25.1 (K), D30.1 (K), D35.1 (K), D40.1 (K), D45.1 (K), D50.1 (K), D55.1 (K), D60.1 (K), D65.1 (K), D70.1 (K), D75.1 (K), U1.21 (PD7)
ROW_SWITCH1: D1.2 (A), MX1.2 (ROW), RE1.S1
ROW_SWITCH2: D71.2 (A), MX71.2 (ROW), RE2.S1
SCK: J1.3 (SCK), U1.8 (PB7)
VCC: F1.2, USB1.A4 (VBUS), USB1.A9 (VBUS), USB1.B4 (VBUS), USB1.B9 (VBUS)

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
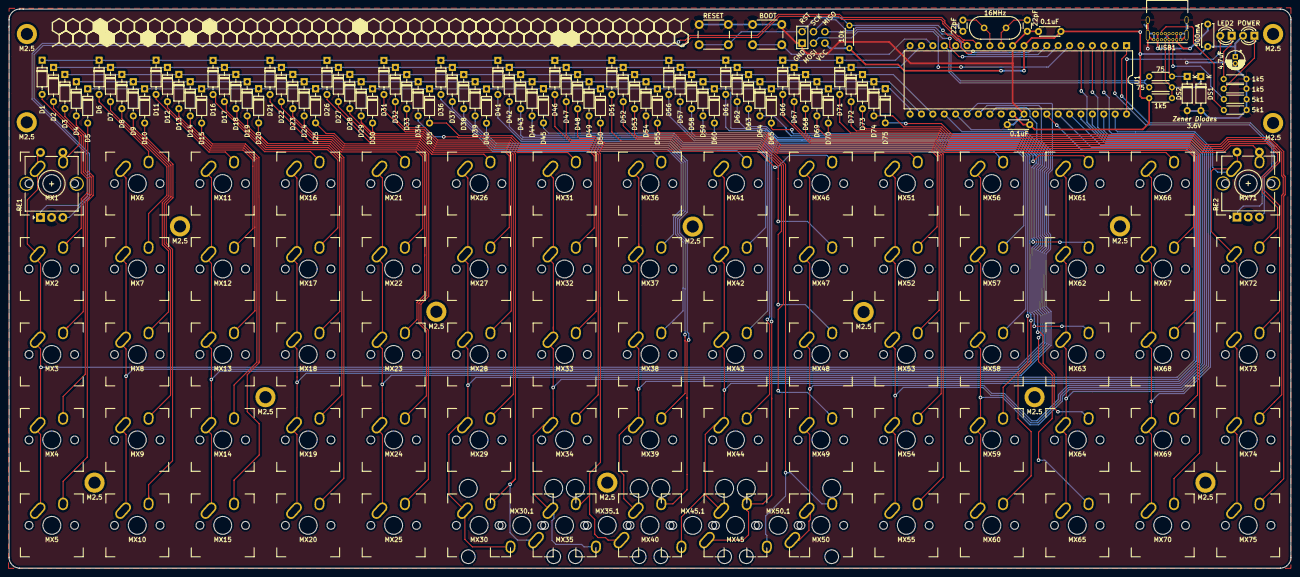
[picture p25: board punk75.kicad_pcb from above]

Board: 2 copper layers, 285.8 x 124.6 mm, 194 parts (0 on the bottom side), 118 nets.

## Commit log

2020-05-10 pcb files
    [punk75.kicad_pcb, punk75.sch]
2020-05-10 added extra switches to allow 2u in bottom row
    [punk75.kicad_pcb, punk75.sch]
2020-05-11 added BOM file with components
    [punk75_BOM.ods]
2020-05-11 added supplier for usb-c sockets
    [punk75_BOM.ods]
2020-05-11 changed usb tracks using differential pair
    [punk75.kicad_pcb, punk75.sch]
2020-05-11 added extra decoration
    [punk75.kicad_pcb]
2020-05-11 added BOM list to readme and images
    [punk75_BOM.ods]
2020-05-12 updated images and added wiring diagram in pdf
2020-05-14 changed MX-1U-NoLED footprint to be one oval one instead of two overlaped
2020-05-14 changed switch footprint lib back to hybrid alps-mx
2020-05-14 adjusted footprint to support millmax
2020-05-16 my MX_Alps footprint lib
2020-05-17 changed switches lib to my modded branch
2020-05-17 changed footprints to my modded MX-Alps hybrids
    [punk75.kicad_pcb, punk75.sch]
2020-05-17 added configurable led and rewired all colums to new ports
    [punk75.kicad_pcb, punk75.sch]
2020-05-18 added 2 rotary encoders and changed some traces to use them
    [punk75.kicad_pcb, punk75.sch]
2020-05-19 fixed silkS of LED2 resistor
    [punk75.kicad_pcb]
2020-05-19 changed filled zones to have thermal reliefs for easier soldering
    [punk75.kicad_pcb]
2020-05-20 added 3d model for usbc connector
    [punk75.kicad_pcb]
2020-05-20 removed old custom footprints
2020-05-20 moved usb-c closer to edge
    now it protudes a bit for easier usage
    added missing 3d models for dip socket and ISP header
    [punk75.kicad_pcb]
2020-05-20 added 3dmodels for rotary encoder and cherry mx
    [asm_mx_asm_PCB.stp, punk75.kicad_pcb]
2020-05-20 added 3d switches to all switches(except one rotary encoder)
    [punk75.kicad_pcb]
2020-05-20 added two more mounting holes and moved other two
    [punk75.kicad_pcb, punk75.sch]
2020-05-20 updated switches footprint lib
2020-05-20 moved images, 3dmodel of switches and step file
    [punk75.kicad_pcb]
2020-05-20 organized in folders
    [punk75.kicad_pcb]
2020-05-20 step with pcb only
2020-05-20 updated pcb with stabs
    [punk75.kicad_pcb]
2020-05-20 fixed the 3dmodels
    [punk75.kicad_pcb]
2020-05-20 3dmodel for usb fixed
    [punk75.kicad_pcb]
2020-05-20 added gerber files
    [punk75-B_Cu.gbr, punk75-B_Mask.gbr, punk75-B_SilkS.gbr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]
2020-05-20 gerber zip
2020-05-21 rerouted crystal zone with better shielding
    [punk75.kicad_pcb]
2020-05-21 makefile creates step model of pcb w/o any component
2020-05-21 moved holes(again...)
    [punk75-B_Cu.gbr, punk75-B_Mask.gbr, punk75-B_SilkS.gbr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]
2020-05-21 fixed keep-out zone in crystal surroundings
    [punk75-B_Cu.gbr, punk75-B_Mask.gbr, punk75-B_SilkS.gbr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]
2020-06-10 case files and render
    [bottom.dxf, closed.dxf, open.dxf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]
2020-06-10 moved case generated to case folder
    [bottom.dxf, closed.dxf, open.dxf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]
2020-06-10 added the renamed folder
    [bottom.dxf, closed.dxf, open.dxf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]
2020-06-10 added README for HI-PRO case
2020-06-16 new plate and bottom with holes
    [bottom.dxf, plate.dxf]
2020-06-16 added bottom and plate(WIP) pcb files
    [punk75-B_Cu.gbr, punk75-B_Mask.gbr, punk75-B_SilkS.gbr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]
2020-06-16 plate now have the holes(WIP round corners)
    [punk75_plate-B_Cu.gbr, punk75_plate-B_Mask.gbr, punk75_plate-B_SilkS.gbr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]
2020-06-16 inner layer pcb
    [punk75_inner-B_Cu.gbr, punk75_inner-B_Mask.gbr, punk75_inner-B_SilkS.gbr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]
2020-06-16 fixed plate dimensions and rounder corners
    [plate.dxf]
2020-06-16 pcb plate
    [punk75_plate-B_Cu.gbr, punk75_plate-B_Mask.gbr, punk75_plate-B_SilkS.gbr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]
2020-06-17 bottom pcb plate graphics and photos
    [punk75_bottom-B_Cu.gbr, punk75_bottom-B_Mask.gbr, punk75_bottom-B_SilkS.gbr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]
2020-06-17 same for plate
    [punk75_plate-B_Cu.gbr, punk75_plate-B_Mask.gbr, punk75_plate-B_SilkS.gbr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]
2020-06-17 fixed silk of pcb
    [punk75-B_Cu.gbr, punk75-B_Mask.gbr, punk75-B_SilkS.gbr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]
2020-06-18 bottom silk lines wider
    [punk75_bottom-B_Cu.gbr, punk75_bottom-B_Mask.gbr, punk75_bottom-B_SilkS.gbr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]
2020-06-18 fixed plate upper lip to be >3mm
    [plate.dxf]
2020-06-18 plate change made in the pcb
    [punk75_plate-B_Cu.gbr, punk75_plate-B_Mask.gbr, punk75_plate-B_SilkS.gbr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]
2020-06-22 fixed plate and inner holes
    [punk75_inner-B_Cu.gbr, punk75_inner-B_Mask.gbr, punk75_inner-B_SilkS.gbr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]
2020-06-22 fixed bottom as well removing cuts under footprints
    [punk75_bottom-B_Cu.gbr, punk75_bottom-B_Mask.gbr, punk75_bottom-B_SilkS.gbr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]
2020-07-15 readme for PCB case
2020-07-15 files of pcb case
2020-07-15 files for pcb case
    [shield.dxf]
2020-07-15 encoder note
2020-07-19 added half-shield acrylic dxf for low-pro cases
    [half-shield.dxf]
2021-01-27 added image of completed keyboard with new keycaps and full case
2021-02-10 Added Simple High Profile 3D Printed Case
    [Punk75 HP - Left Side.step, Punk75 HP - Left Side.stl, Punk75 HP - Right Side.step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]
2021-02-10 Added assembly instructions for 3d printed case designs
2021-02-10 Added note about 3d printed cases using the half shield dxf
